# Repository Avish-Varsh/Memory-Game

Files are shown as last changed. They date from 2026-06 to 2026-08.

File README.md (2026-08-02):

# Simon-style Retro Memory Game 

# Project Status

✅ **Full release** 

## Current version

**Version: v1.1.0**

_Latest update: High-score storage_

Current features:
- 100 levels 
- High-score storage
- Fully playable game loop
- Random sequence generation
- Player input validation
- Progressive difficulty
- Win/Loss sequences 
- Unique audio feedback on player input
- Startup melody 
- Custom multi level with visible circuit design PCB
- Battery powered usability 

## Overview

This project is a Simon-style memory game built using an Arduino Uno. The player must memorize and repeat an increasingly long sequence of colored LEDs using the corresponding push buttons.

The project focuses on embedded systems programming, finite state machines, input validation, timing control and modular code design. It is being developed incrementally, with each version introducing new gameplay mechanics and hardware features. Development is being tracked using Git for versioning to document project progression.

📹 **[Gameplay Demo (Breadboard)](evidence/demo_v1.mp4)**

## Important Note
To make sure this project is accessible to as many people as possible. I have used an visible circuit design without a proper enclosure and rather used the PCB itself as an enclosure to preserve the retro feel of the product and ensure anyone with any kind of components can create and use it. As the a case would require strict measurements and only certain parts to be used. I don't intend to turn this into a consumer grade product, if anyone feels like they would like to please fell free as long as you credit me in the design.  

## Gameplay Overview:
At startup, a random sequence of LEDs is displayed. The player must replicate the sequence using the corresponding colored buttons. Each successful round increases the difficulty by extending the sequence length and increasing the playback speed. If the player enters an incorrect sequence at any point, the game ends and they must restart the game.

## Bill of Materials (BOM)

| Qty | Component | Value / Part | Description |
|---:|---|---|---|
| 1 | Arduino Nano | Arduino Nano v3.x | Main microcontroller |
| 1 | 9 V Battery | — | Power source |
| 1 | Piezo Buzzer | — | Polarized buzzer for audio feedback |
| 1 | Red LED | — | Visual feedback |
| 1 | Green LED | — | Visual feedback |
| 1 | Blue LED | — | Visual feedback |
| 3 | Resistors | 220 Ω | Current-limiting resistors for LEDs |
| 1 | 10 kΩ Potentiometer | B10K | Linear potentiometer |
| 1 | Red Push Button | SW_Push | User input |
| 1 | Green Push Button | SW_Push | User input |
| 1 | Blue Push Button | SW_Push | User input |
| 1 | Power Switch | SPST | Main power switch |
| 1 | 1×8 Pin Header | Male | Board-to-board connector |
| 1 | 1×8 Socket Header | Female | Board-to-board connector |
| 1 | 1×1 Pin Header | Male | Single-pin connector |
| 1 | 1×1 Socket Header | Female | Single-pin connector |

# Progress Roadmap:

## Section 1: Planning

* [x] Define project concept
* [x] Select components
* [x] Create GitHub repository
* [x] Create initial project structure
* [x] Draft wiring schematic

## Section 2: Core Hardware

* [x] Connect LEDs and verify operation
* [x] Connect buttons and verify input
* [x] Connect buzzer and verify sound output
* [x] Build and test complete circuit

## Section 3: Core Game Logic

* [x] Generate random sequences
* [x] Display sequence to player
* [x] Read player input
* [x] Validate player input
* [x] Implement win/lose conditions
* [x] Add score tracking
* [x] Add correct game progression

## Section 4: Difficulty System

* [x] Increase sequence length each level
* [x] Add potentiometer to control LED blink speed
* [x] Balance game difficulty

## Section 5: Audio Feedback

* [x] Add unique tones for each button
* [x] Add correct input feedback
* [x] Add loss melody
* [x] Add startup melody
* [x] Add win melody

## Section 6: Enclosure Design 

* [x] Create initial enclosure concept
* [x] Design button layout
* [x] Design LED placement
* [x] Create custom PCB
* [x] Create enclosure v1
* [x] Refine enclosure based on testing
* [x] Finalize enclosure design

## Section 7: Testing & Optimization

* [x] Test all game functions
* [x] Fix identified bugs
* [x] Improve code organization
* [x] Perform final hardware verification

## Section 8: Documentation

* [x] Create final schematic
* [x] Add circuit images
* [x] Add project photos
* [x] Document challenges faced
* [x] Document lessons learned
* [x] Complete README

## Challenges Faced

- Designing a reliable input validation system while preventing accidental multiple button presses.
- Debugging state transition issues that caused the game logic to become inconsistent.
- Resolving timing conflicts between LED animations and player input.
- Preventing invalid variable values caused by unintended state changes.
- Structuring the code into reusable functions to improve maintainability.
- Finding accurate part footprints.
- Aligning parts to create multi level PCB
- Making sure High-score was only set to 0 on first boot. 

> Additional challenges will be documented as development continues.

## Skills Learned

- Finite State Machine (FSM) design
- Edge detection for button input
- Software debouncing techniques
- Modular programming using custom functions
- Enum-based state management
- Switch-case driven program flow
- Random sequence generation
- Timing management using millis()
- Debugging embedded software
- Hardware/software integration
- Multi level PCB design 
- Using EEPROM for storage of important variables.  

> Additional skills will be documented as development continues.

## Section 9: Future Improvements
* [x] Add  EEPROM to save important user data such as high scores
* [ ] Add LCD for live feedback
* [ ] Create custom win/loss screens for the LCD
* [ ] Add an LED matrix to increase difficulty as sequences can come from a bigger space and in a harder to remember pattern
* [ ] Add a charging feature to improve portability
* [ ] Multiple gameplay modes
* [ ] Use ESP32 instead of Arduino to link the game to an online leaderboard

## Images

### Hardware Prototype v1

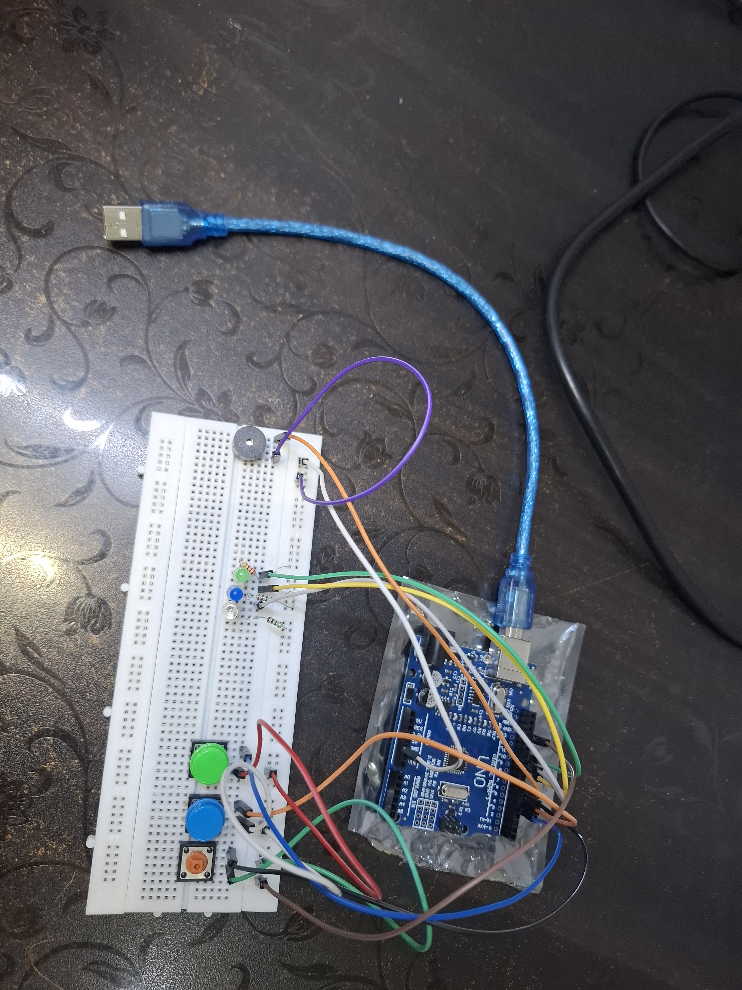
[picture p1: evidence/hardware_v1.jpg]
Hardware Prototype v1


### Hardware Prototype v2

Hardware Prototype v2

## Version History

### v1.1.0
- Maximum 100 levels
- High-score storage 

### v1.0.0
- Multi level PCB
- Visible circuit design

### v0.6.0
- Custom PCB 
- Battery power 

### v0.5.0
- Added unique audio feedback for each button
- Added startup melody
- Added win melody
- Added loss melody
- Integrated audio feedback into gameplay

### v0.4.0
- Playable beta release
- Added input validation
- Added win/lose sequences
- Improved game progression

### v0.3.0
- Added score tracking
- Added progressive difficulty using random sequences that increase in length after each successful round 
- Added a potentiometer to control LED speed

### v0.2.0
- Initial hardware prototype and schematic

### v0.1.0
- Initial planning

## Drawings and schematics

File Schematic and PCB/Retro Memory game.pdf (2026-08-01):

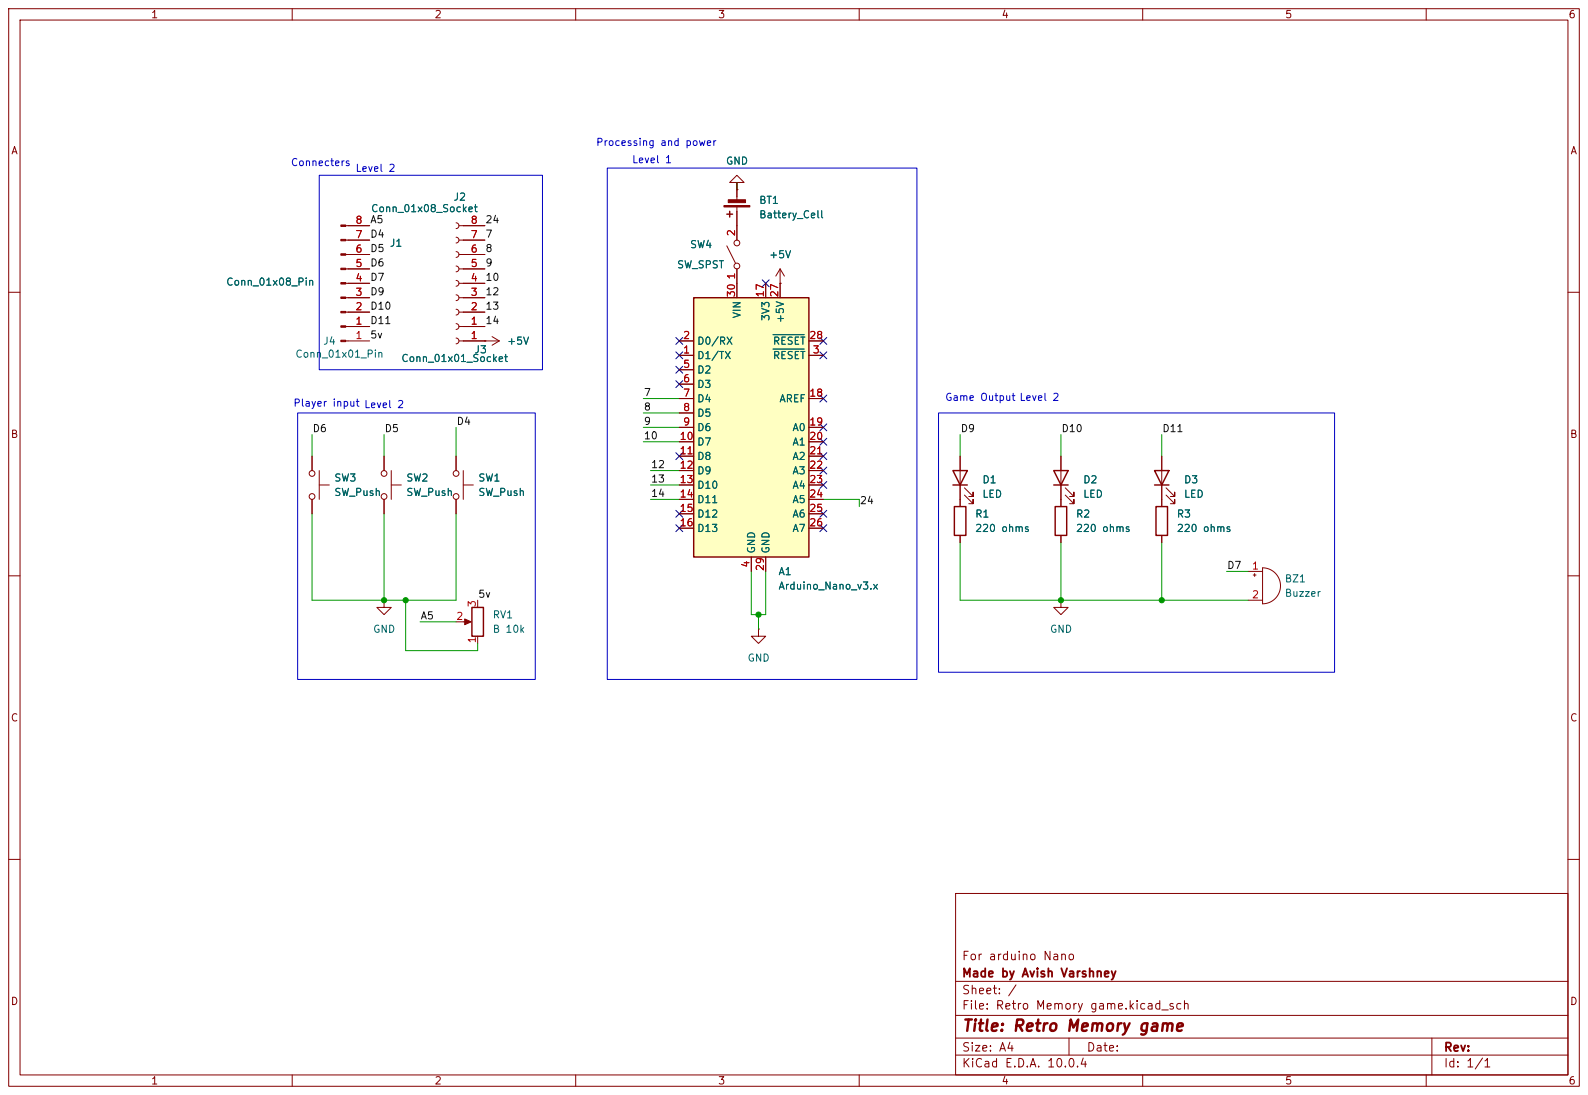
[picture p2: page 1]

For arduino Nano
Made by Avish Varshney
Sheet: /
File: Retro Memory game.kicad_sch
Title: Retro Memory game

Size: A4 | Rev:
KiCad E.D.A. 10.0.4 | Id: 1/1

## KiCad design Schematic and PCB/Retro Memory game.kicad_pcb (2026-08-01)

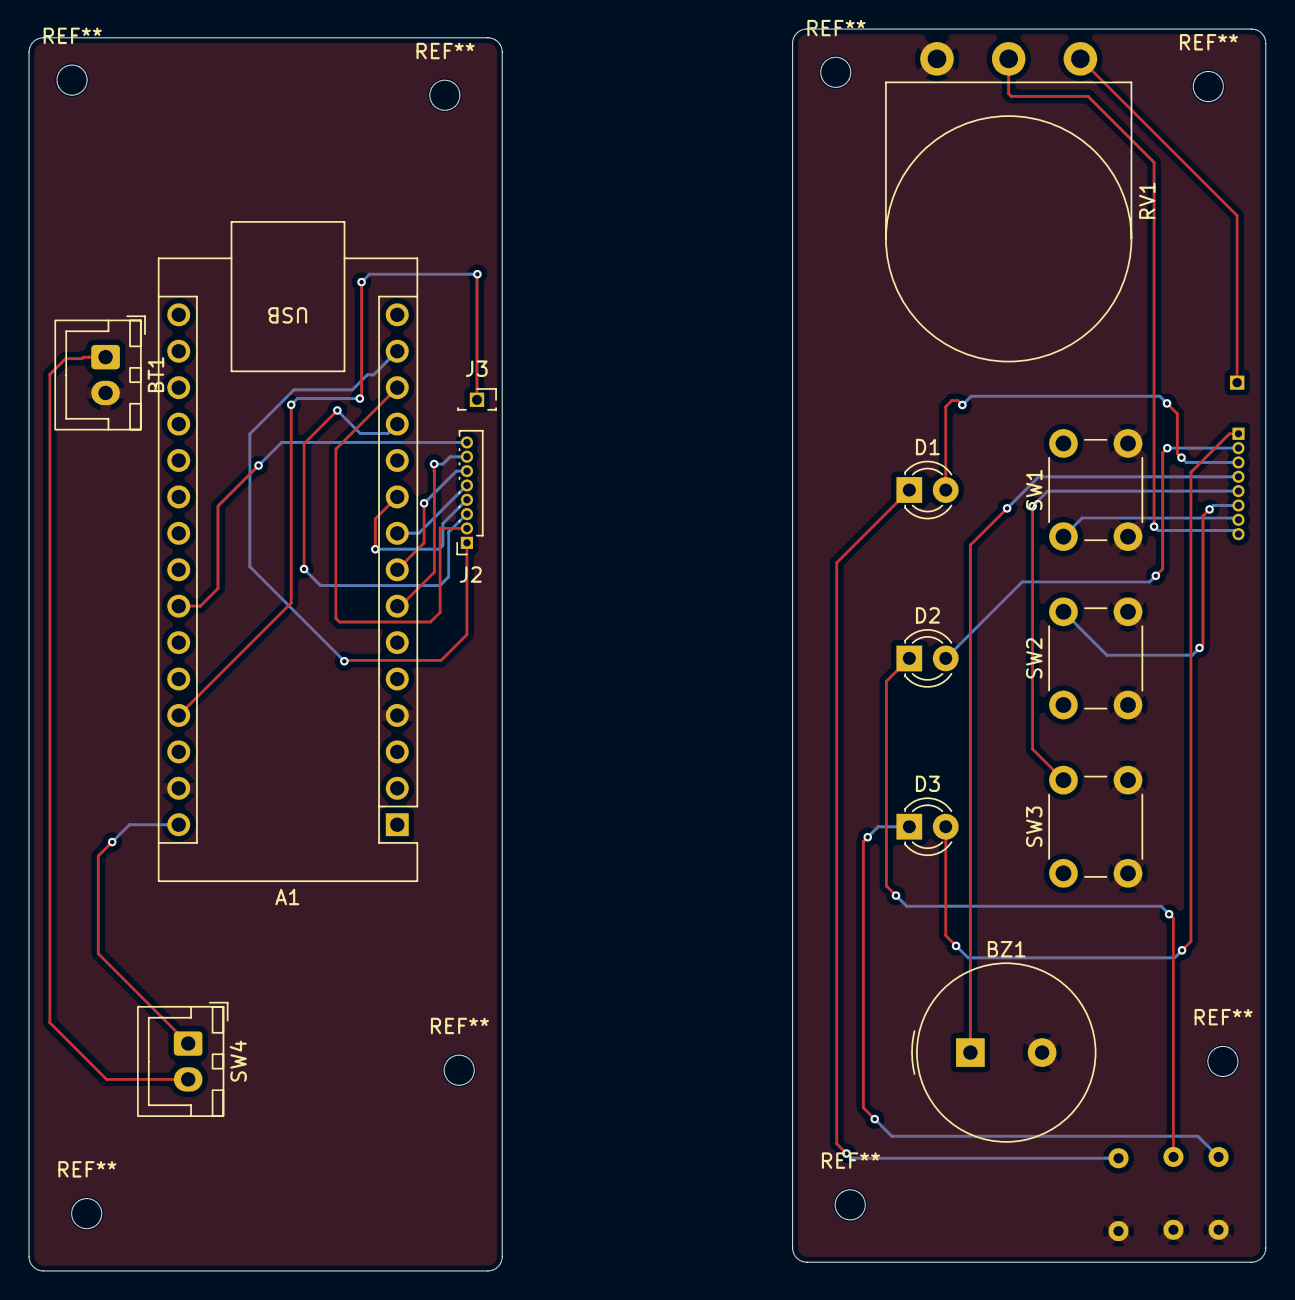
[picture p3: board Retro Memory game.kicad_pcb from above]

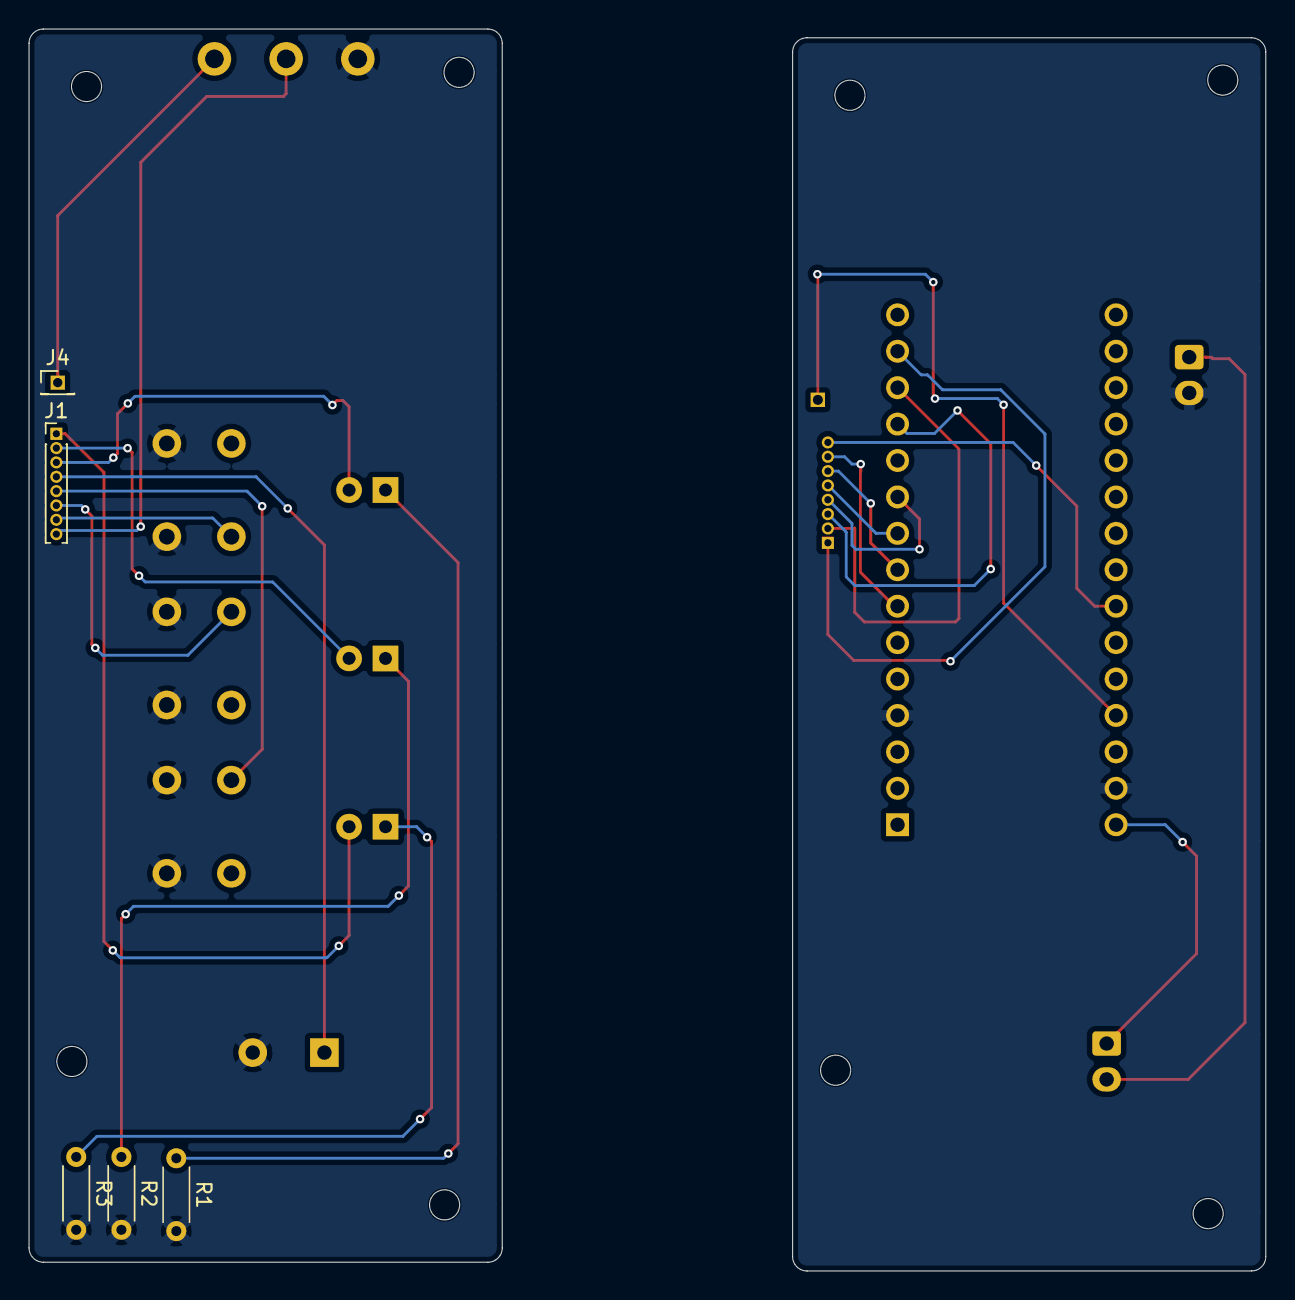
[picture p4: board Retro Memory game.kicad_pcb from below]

Board: 2 copper layers, 86.2 x 86.6 mm, 18 parts (5 on the bottom side), 24 nets.

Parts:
A1: Arduino_Nano_v3.x; Arduino_Nano
BT1: Battery_Cell; JST_XH_B2B-XH-A_1x02_P2.50mm_Vertical
BZ1: Buzzer; Buzzer_TDK_PS1240P02BT_D12.2mm_H6.5mm
D1, D2, D3: LED; LED_D3.0mm
J1: Conn_01x08_Pin; PinHeader_1x08_P1.00mm_Vertical
J2: Conn_01x08_Socket; PinSocket_1x08_P1.00mm_Vertical
J3: Conn_01x01_Socket; PinSocket_1x01_P1.27mm_Vertical
J4: Conn_01x01_Pin; PinHeader_1x01_P1.27mm_Vertical
R1, R2, R3: 220 ohms; R_Axial_DIN0204_L3.6mm_D1.6mm_P5.08mm_Horizontal
RV1: B 10k; Potentiometer_Omeg_PC16BU_Vertical
SW1, SW2, SW3: SW_Push; SW_PUSH_6mm
SW4: SW_SPST; JST_XH_B2B-XH-A_1x02_P2.50mm_Vertical

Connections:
+5V: A1.27 (+5V), J3.1 (Pin_1_1)
/5v: J4.1 (Pin_1_1), RV1.3
/7: A1.7 (D4), J2.7
/8: A1.8 (D5), J2.6
/9: A1.9 (D6), J2.5
/10: A1.10 (D7), J2.4
/12: A1.12 (D9), J2.3
/13: A1.13 (D10), J2.2
/14: A1.14 (D11), J2.1
/24: A1.24 (A5), J2.8
/A5: J1.8, RV1.2
/D4: J1.7, SW1.1
/D5: J1.6, SW2.1
/D6: J1.5, SW3.1
/D7: BZ1.1 (+), J1.4
/D9: D1.2 (A), J1.3
/D10: D2.2 (A), J1.2
/D11: D3.2 (A), J1.1
GND: A1.4 (GND), A1.29 (GND), BT1.2 (-), BZ1.2 (-), R1.2, R2.2, R3.2, RV1.1, SW1.2, SW2.2, SW3.2
unnamed: A1.30 (VIN), SW4.1 (A)
unnamed: BT1.1 (+), SW4.2 (B)
unnamed: D1.1 (K), R1.1
unnamed: D2.1 (K), R2.1
unnamed: D3.1 (K), R3.1

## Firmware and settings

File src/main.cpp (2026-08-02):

#include <Arduino.h>
#include <EEPROM.h>
int const potenti = A5;
int const leds[3] ={ 9, 10, 11};
 // if leds[0] is green led then btns[0] must also be green btn
int const btns[3] ={ 4, 5, 6};
int const btnnumber = 3; 
int sequence[100]={}; 
int const buzz = 7;
int level;
long m1 = 0; // previous millis
unsigned long m2[btnnumber] = {0,0,0}; //millis for button debounce
unsigned long tonemillis[5] = {0,0,0,0,0}; // stores time for which each tone must play till they change.  
unsigned int debounce = 50;
bool inputflag[btnnumber] = {false, false, false}; // flags to store button state data
bool waspressed[btnnumber] = {false, false, false}; // notes whether btn was pressed before or not
float interval;
bool on; // determines whether led should be on or off
int currentstate;
enum gamestate {store, pattern, user, lose, win}; // possible states for the game
int j; // for leds
int counter; // input counter
bool timer = false;// used to note when the timer is on or off;
bool startup;
bool lost = false;
bool won = false;
int lock = 10; 
int key = 122; // Can be decoded for an easter egg :) 
int scorestore;
int highscore; 
void setup() {
  Serial.begin(9600);
  for(int p = 0; p < 3; p++){
    pinMode(leds[p], OUTPUT);
    pinMode(btns[p], INPUT);
    digitalWrite(btns[p],HIGH);
  }
  pinMode(potenti,INPUT);
  pinMode(buzz, OUTPUT);
  level = 0;
  on = true; 
  currentstate = store;
  j =  0;
  counter = 0;
  randomSeed(analogRead(A0));
  startup = true; 
  if(EEPROM.read(lock) != key){
    EEPROM.put(lock, key);
    EEPROM.put(scorestore,0);
  }
}

void userflag() {
for(int i = 0; i < btnnumber; i++){
 int reading  =  digitalRead(btns[i]);
 if(reading == LOW){
  waspressed[i] = true; 
 }
 if(reading == HIGH && waspressed[i] == true){
  if(timer ==  false){
    m2[i] = millis();
    timer = true; 
  }
 if((millis() - m2[i]) >= debounce && waspressed[i] == true){
  inputflag[i] = true;
  waspressed[i] = false;
  timer = false;
 }
}
}
}

void validateinput(int userinput){
if(userinput == sequence[counter]){
  counter = counter + 1;
  if(userinput == 0){
  tone(buzz,262,10);
  }
  if(userinput == 1){
    tone(buzz,5000,20);
  }
  if(userinput == 2){
    tone(buzz,2000,15);
  }
}else{
  lost = true; 
  currentstate = lose;
}
}

void checkwin(){
  if(counter == (level + 1)){
    won = true; 
    currentstate = win;
  }
}


void flagaction() {
for(int i = 0; i < btnnumber; i++){
  if(inputflag[i] == true){ 
    validateinput(i);
    inputflag[i] = false;
  }
}
}


int picked() {
 return random(3);
}


void loop() {
  if(startup == true){
    tone(buzz,262,180);
    delay(200);
    tone(buzz,392,180);
    delay(200);
    tone(buzz, 523, 180);
    delay(200);
    startup = false; 
  }
  counter = constrain(counter, 0, 101); 
  j = constrain(j, 0, 101);
  level = constrain(level, 0, 100); 
  highscore = constrain(level, 0 , 100); // max 100 levels
  interval = (600 + (analogRead(potenti)/2));
  switch(currentstate){
    case store:
     sequence[level] = constrain(picked(), 0 , 2); 
     currentstate = pattern;
     break;
    case pattern:
     if(on == true){
       digitalWrite(leds[sequence[j]],HIGH);
       if(millis() - m1 >= interval){
         m1 = millis();
         digitalWrite(leds[sequence[j]],LOW);
         on = false;
        }
      }
      if(on == false && (millis() - m1 >= 500)){
          on = true;
          j = j + 1;
        }
      if( j == (level+1)){
        currentstate = user;
      }
      break;
    case user:
    userflag();
    flagaction();
    checkwin();
    break;
    case lose: 
    if(lost == true){
      tone(buzz,5000,60);
      tonemillis[0] = millis() + 80;
      lost = false;
    }
    if(millis() == tonemillis[0]){
      tone(buzz,1800,80);
      tonemillis[1] = millis() + 100;
    }
    if(millis() == tonemillis[1]){
      tone(buzz,800,80);
      tonemillis[2] = millis() + 100;
    }
    if(millis() == tonemillis[2]){
      tone(buzz,350,60);
      tonemillis[3] = millis() + 80;
    }
    if(millis() == tonemillis[3]){
      tone(buzz,180,80);
      tonemillis[4] = millis() + 80;
    }
    if(millis() == tonemillis[4]){
      Serial.println("You lose start from begining.");
      Serial.print("Score:");
      Serial.println(level);
      if(EEPROM.read(scorestore) < level){
        highscore = level;
        EEPROM.put(scorestore, highscore);
        Serial.println("New Highscore!!!");
        Serial.println(highscore);
      }
      level = 0;
      counter = 0;
      j = 0;
      m1 = millis();
      currentstate = pattern;
      break; 
    }
    break;
    case win:
    if(won == true){
      tone(buzz,523,60);
      tonemillis[0] =  millis() + 80;
      won = false;
    }
    if(millis() == tonemillis[0]){
      tone(buzz,1000,80);
      tonemillis[1] = millis() + 100;
    }
    if(millis() == tonemillis[1]){
      tone(buzz,2000,80);
      tonemillis[2] = millis() + 100;
    }
    if(millis() == tonemillis[2]){
      tone(buzz,3500,80);
      tonemillis[3] = millis() + 100;
    }
    if(millis() == tonemillis[3]){
      tone(buzz,5000,80);
      tonemillis[4] = millis() + 80;
    }
    if(millis() == tonemillis[4]){
      Serial.println("You win entering new level");
      j = 0;
      counter = 0;
      level = level + 1;
      Serial.print("level:");  
      Serial.println(level);
      m1 = millis();
      currentstate = store; 
      break;
    }
    break;
  }
}

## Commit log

2026-06-24 Add schematic and Hardware v1 picture Complete v0.2.0
2026-06-25 Add led sequence and potentiometer v0.3.0
2026-07-17 Custom PCB v0.6.0
    [Memory Game.kicad_pcb]
2026-08-01 v1.0.0 Full release
    [Memory Game.kicad_pcb, Retro Memory game.kicad_pcb]
